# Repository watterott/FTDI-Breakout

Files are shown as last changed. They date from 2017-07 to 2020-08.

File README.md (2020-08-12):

# FTDI-Breakout
The FTDI-Breakout is an USB to Serial Adapter with FTDI Chipset.

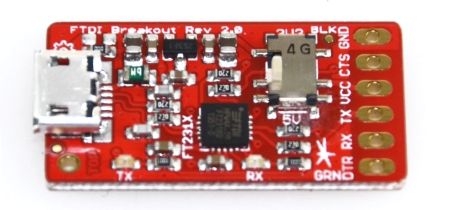
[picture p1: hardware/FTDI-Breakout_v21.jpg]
FTDI-Breakout v2

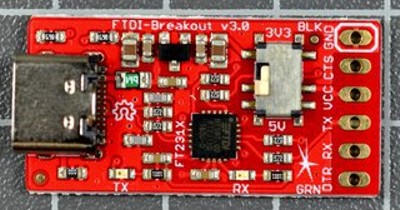
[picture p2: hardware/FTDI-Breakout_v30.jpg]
FTDI-Breakout v3


* [FTDI FT231X](https://www.ftdichip.com/Products/ICs/FT231X.html) USB UART Bridge (up to 1M baud)
* 3.3V or 5V logic supply voltage selectable by switch
* Rx + Tx Status LEDs
* Overcurrent protection (resettable polyswitch fuse)
* Standard 6 pin connector with GND, CTS, VCC, TX, RX, DTR
* USB connector
* Open-Source and released under the [Creative Commons Attribution Share-Alike License](https://creativecommons.org/licenses/by-sa/4.0/).
* **[Documentation on learn.watterott.com](https://learn.watterott.com)**

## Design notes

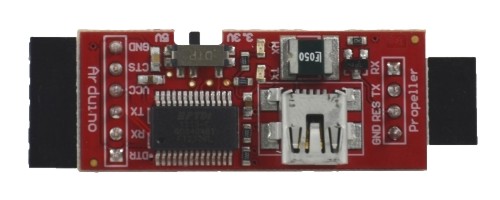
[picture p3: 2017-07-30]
hardware/FTDI-Breakout_v12.jpg

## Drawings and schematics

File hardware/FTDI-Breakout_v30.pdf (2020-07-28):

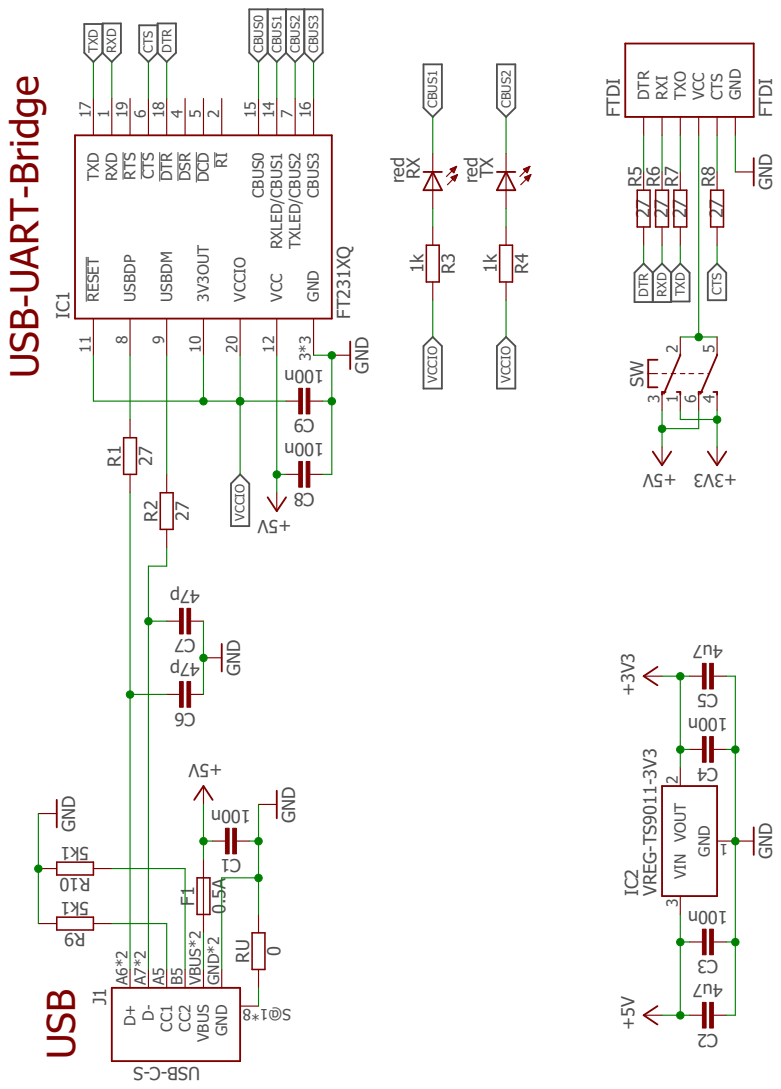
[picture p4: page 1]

Released under the Creative Commons Attribution Share-Alike

Watterott Watterott OS HW CE WEEE

License. http://creativecommons.org/licenses/by-sa/4.0/ Designed by Andreas Watterott (Watterott electronic)

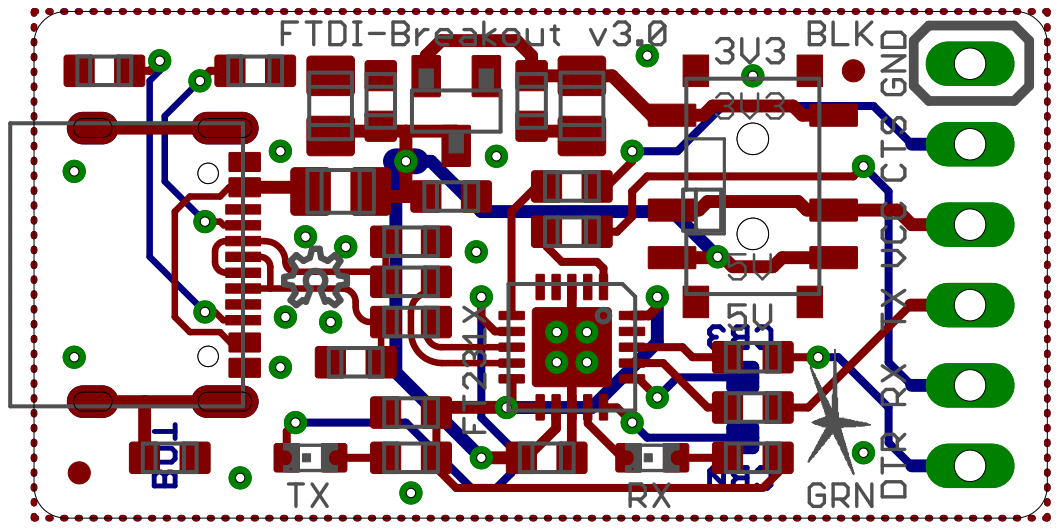
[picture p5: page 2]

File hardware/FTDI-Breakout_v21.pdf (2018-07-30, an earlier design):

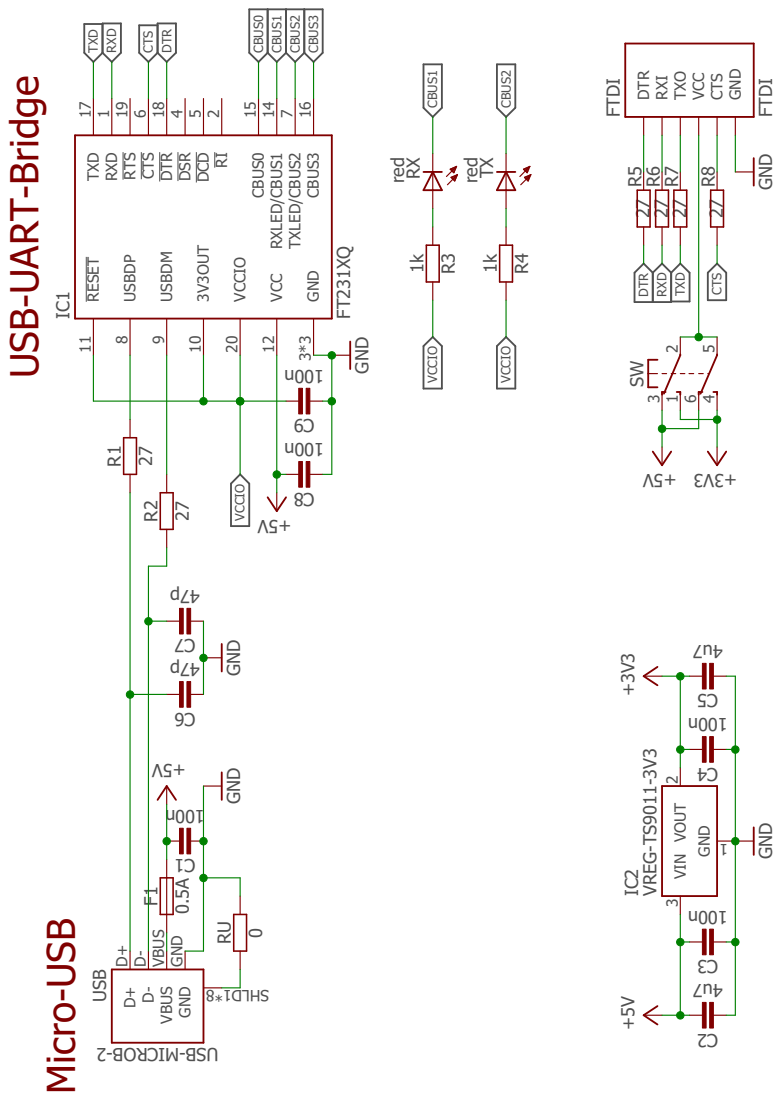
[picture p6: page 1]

FT231XQ 0.5A V5 + GND GND V5 + GND +3V3 +5V 27272727 GND V5 + 3V3 + n001 n001 7u4 27 27 n001 0 red 1k red 1k n001 n001 7u4 p74 p74 GND VREG-TS9011-3V3 Released under the Creative Commons Attribution Share-Alike License. http://creativecommons.org/licenses/by-sa/4.0/ Designed by Andreas Watterott (Watterott electronic) IC13V3OUT 10 USBDM 9 USBDP 8 RESET 11 GND 3*3 TXD 17 RXD 1 RTS 19 CTS 6 DTR 18 DSR 4 DCD 5 RI 2 CBUS0 15 VCCIO 20 VCC 12 RXLED/CBUS1 14 TXLED/CBUS2 7 CBUS3 16 F1 D+ D+ D- D- VBUS VBUS GND GND USB 2- BORCI M- BSU8*1DL HS FTDI FTDI DTR RXI TXO VCC CTS GND 2 31 SW 5 64 R5R6R7R8 3C4C5C R1 R2 1C RU RX R3 TX R4 8C9C 2C 6C7C IC2 GND VIN 3 V1 OUT 2 Watterott Watterott OS HW CE WEEE VCCIO VCCIO VCCIO CTS CTS DTR DTR CBUS0 CBUS1 CBUS1 CBUS2 CBUS2 CBUS3 TXD TXD RXD RXD USB-UART-Bridge Micro-USB ABCD 1 2 3 4 5 6 ABCD 1 2 3 4 5 6

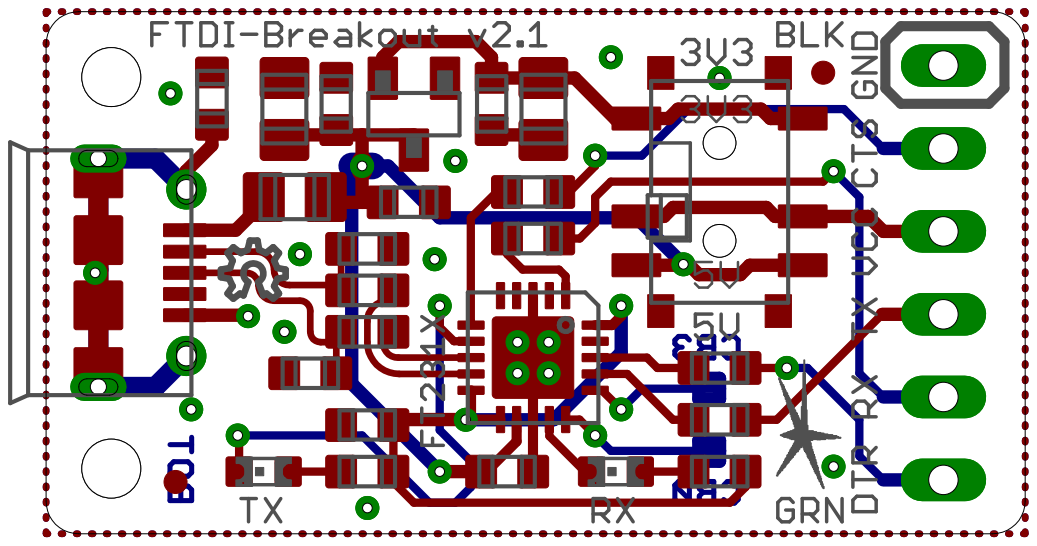
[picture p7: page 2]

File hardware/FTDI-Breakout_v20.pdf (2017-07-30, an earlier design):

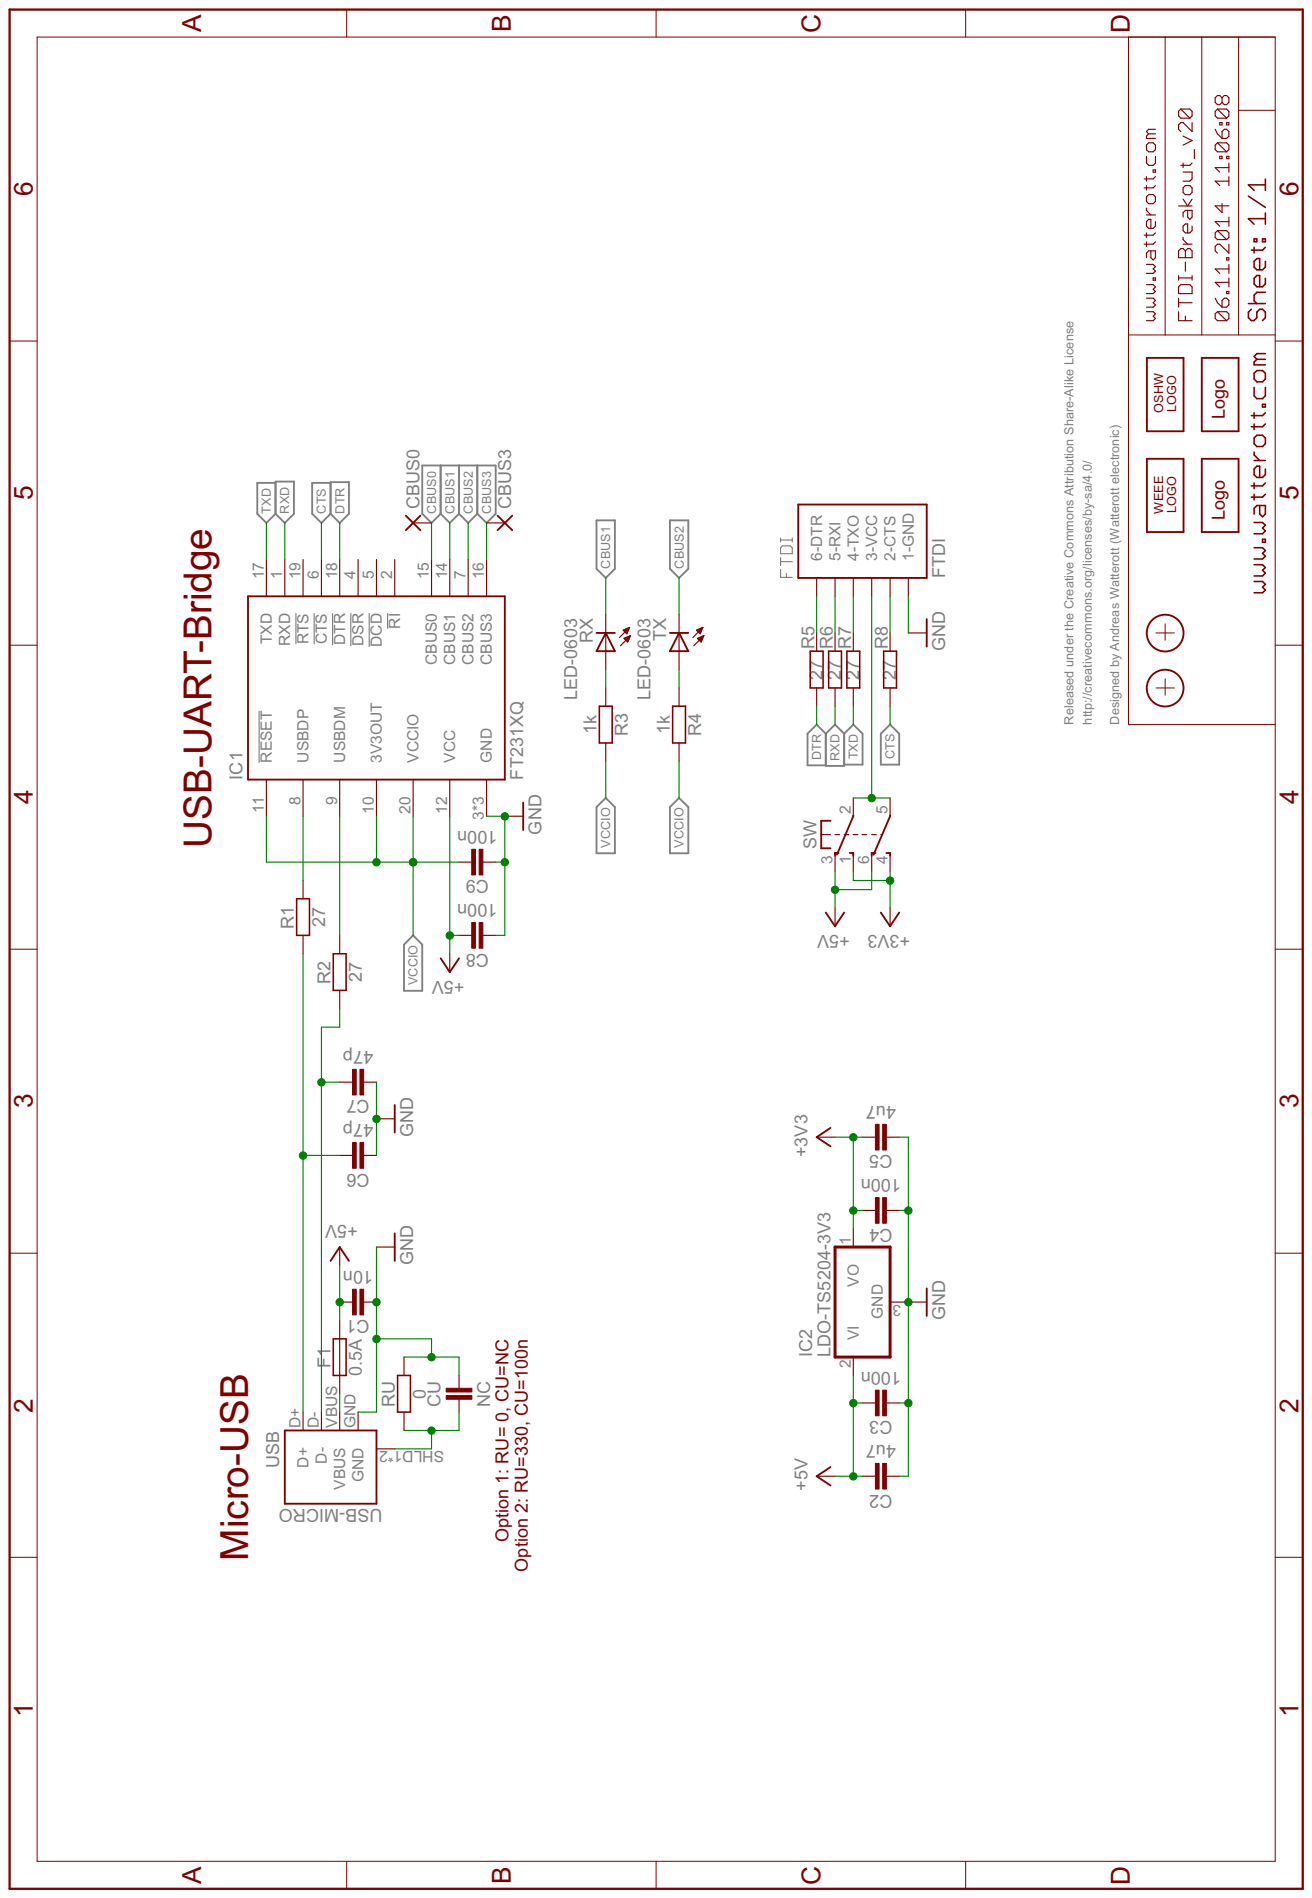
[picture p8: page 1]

FT231XQ LDO-TS5204-3V3 0.5A V5+ GND GND V5+ GND +3V3 +5V 27272727 GND V5+ 3V3+ n001 n001 7u4 27 27 n01 N0C LED-0603 1k LED-0603 1k n001 n001 7u4 p74 p74 GND Released under the Creative Commons Attribution Share-Alike License http://creativecommons.org/licenses/by-sa/4.0/ Designed by Andreas Watterott (Watterott electronic) IC13V3OUT 10 USBDM 9 USBDP 8 RESET 11 GND 3*3 TXD 17 RXD 1 RTS 19 CTS 6 DTR 18 DSR 4 DCD 5 RI 2 CBUS0 15 VCCIO 20 VCC 12 CBUS1 14 CBUS2 7 CBUS3 16 IC2 GND VI 2 3 VO 1 F1 D+ D+ D- D- VBUS VBUS GND GND USB ORCI M- BSU2* 1DLHS FTDI 6-DTR 5-RXI 4-TXO 3-VCC 2-CTS 1-GND 2 31 SW 5 64 R5R6R7R8 3C4C5C R1 R2 1C CURU RX R3 TX R4 8C9C 2C CBUS0 CBUS3 6C7C VCCIO VCCIO VCCIO CTS CTS DTR DTR CBUS0 CBUS1 CBUS1 CBUS2 CBUS2 CBUS3 TXD TXD RXD RXD Option 1: RU= 0, CU=NC Option 2: RU=330, CU=100n USB-UART-Bridge Micro-USB ABCD 1 2 3 4 5 6 ABCD 1 2 3 4 5 6 OSHW LOGO WEEE LOGO Logo Logo

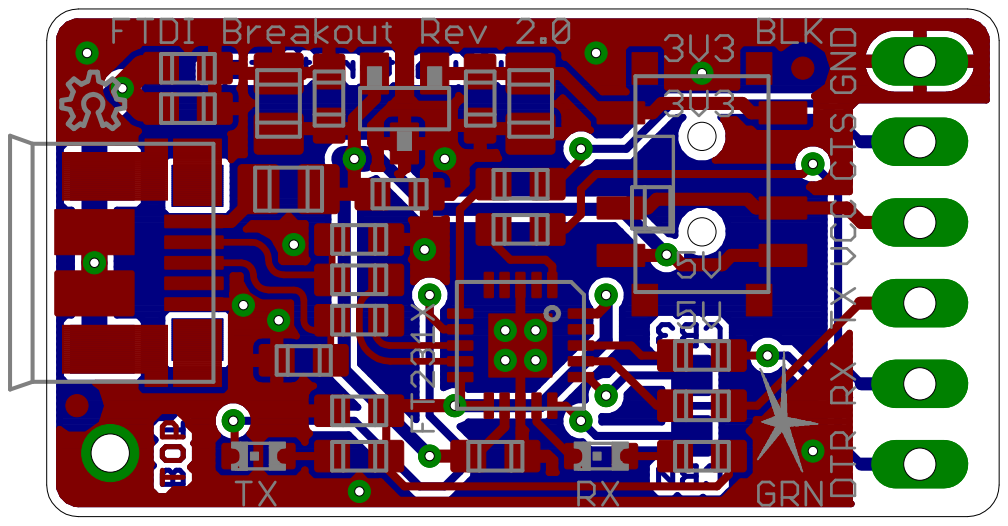
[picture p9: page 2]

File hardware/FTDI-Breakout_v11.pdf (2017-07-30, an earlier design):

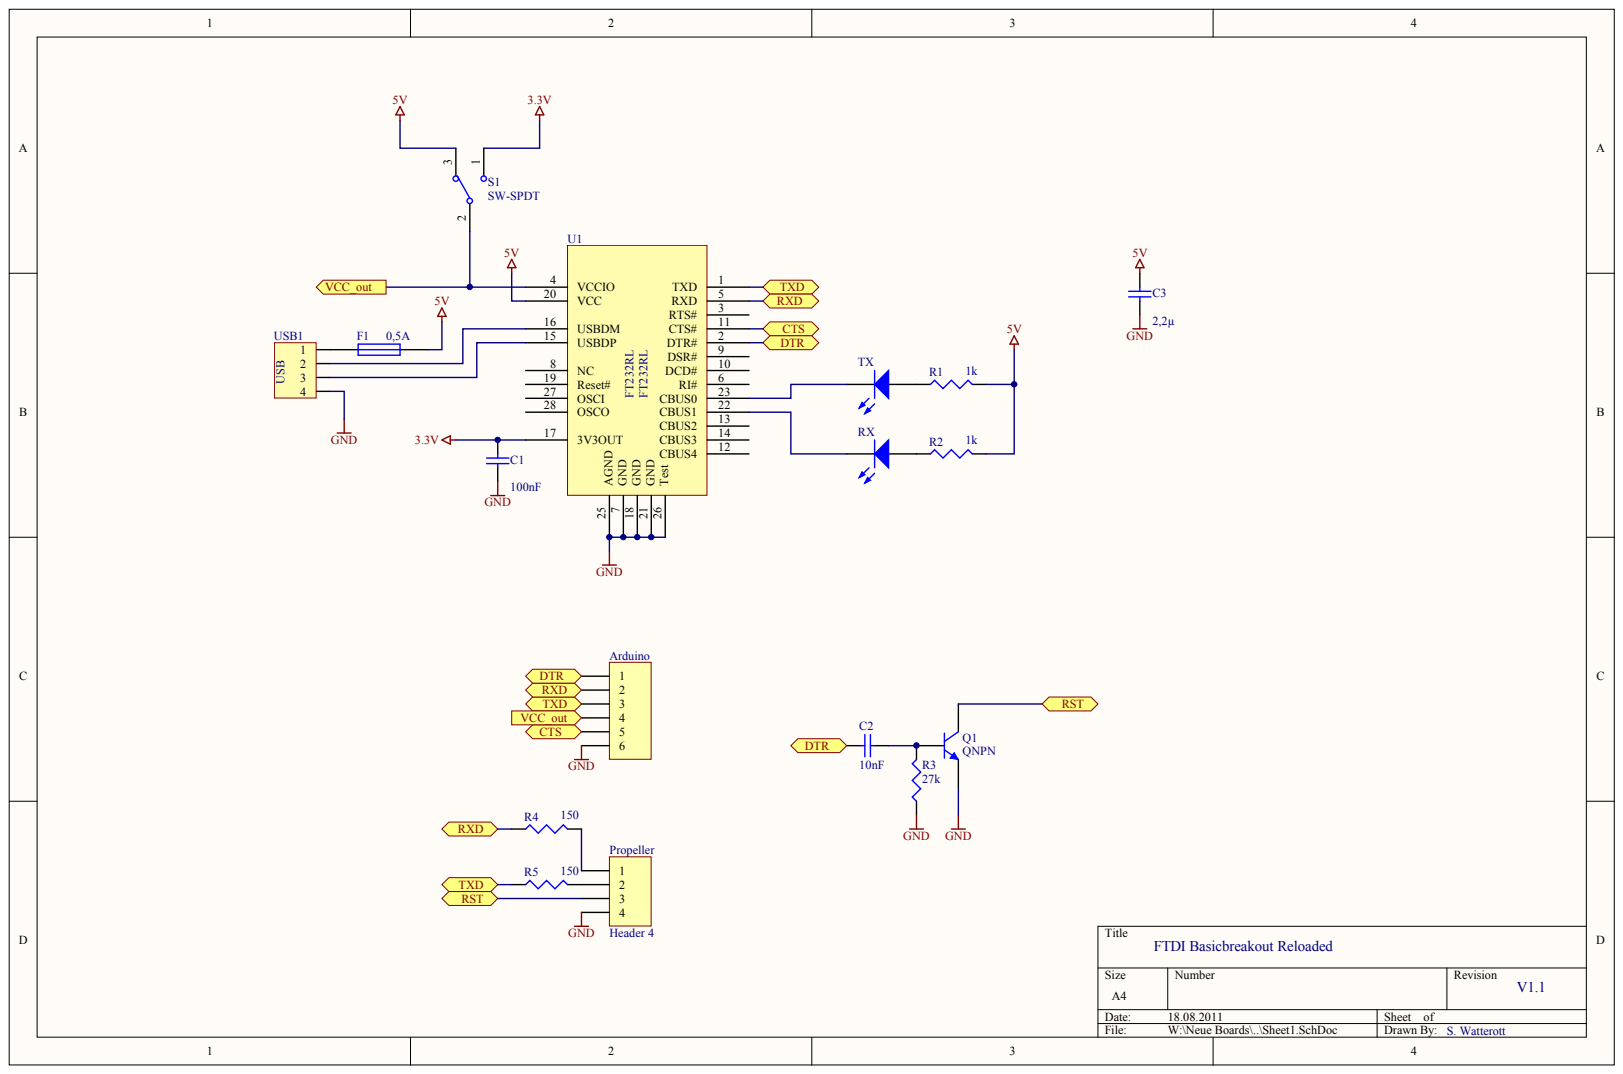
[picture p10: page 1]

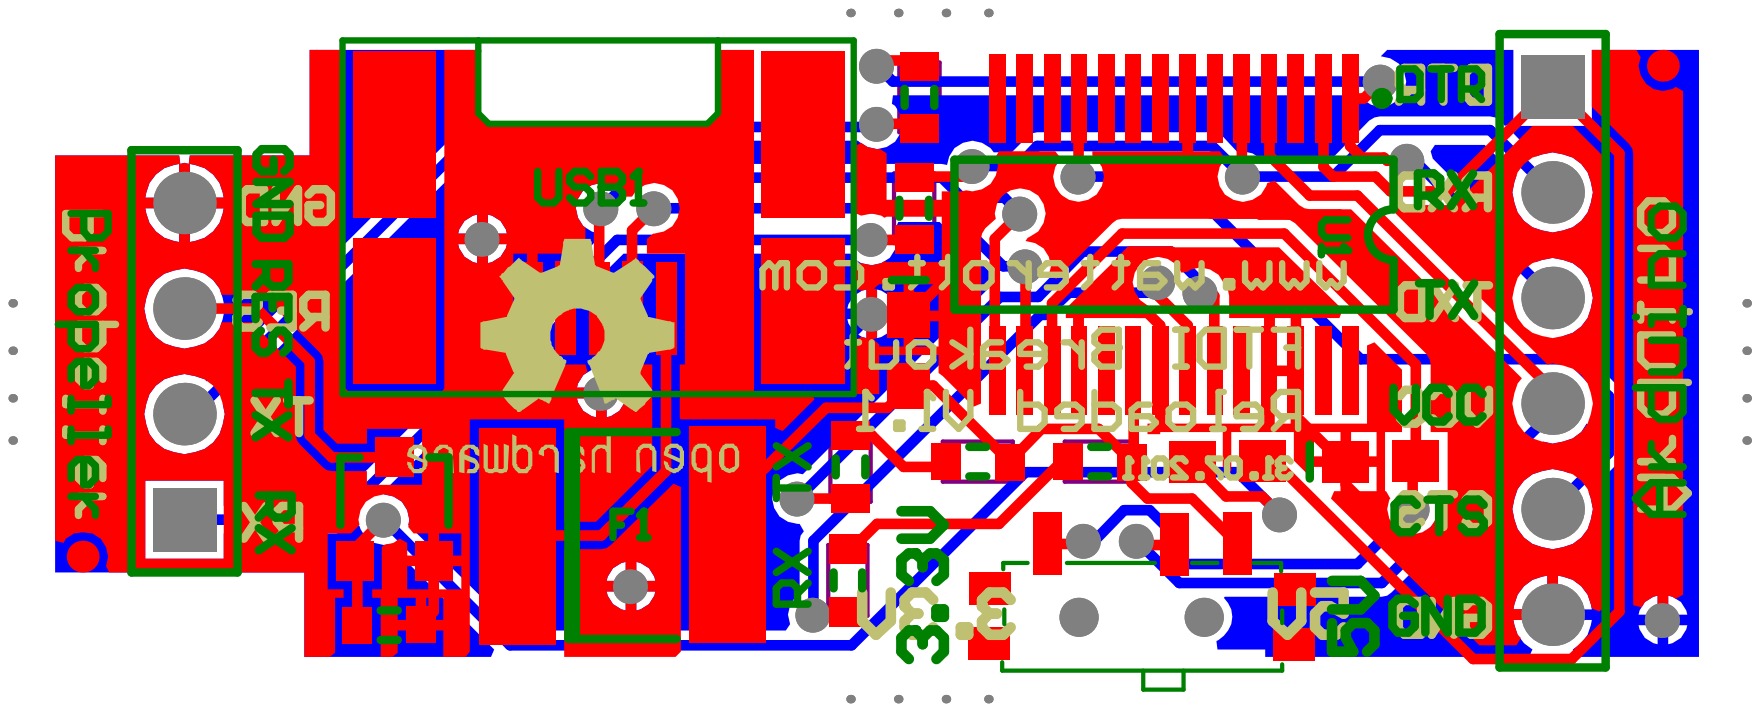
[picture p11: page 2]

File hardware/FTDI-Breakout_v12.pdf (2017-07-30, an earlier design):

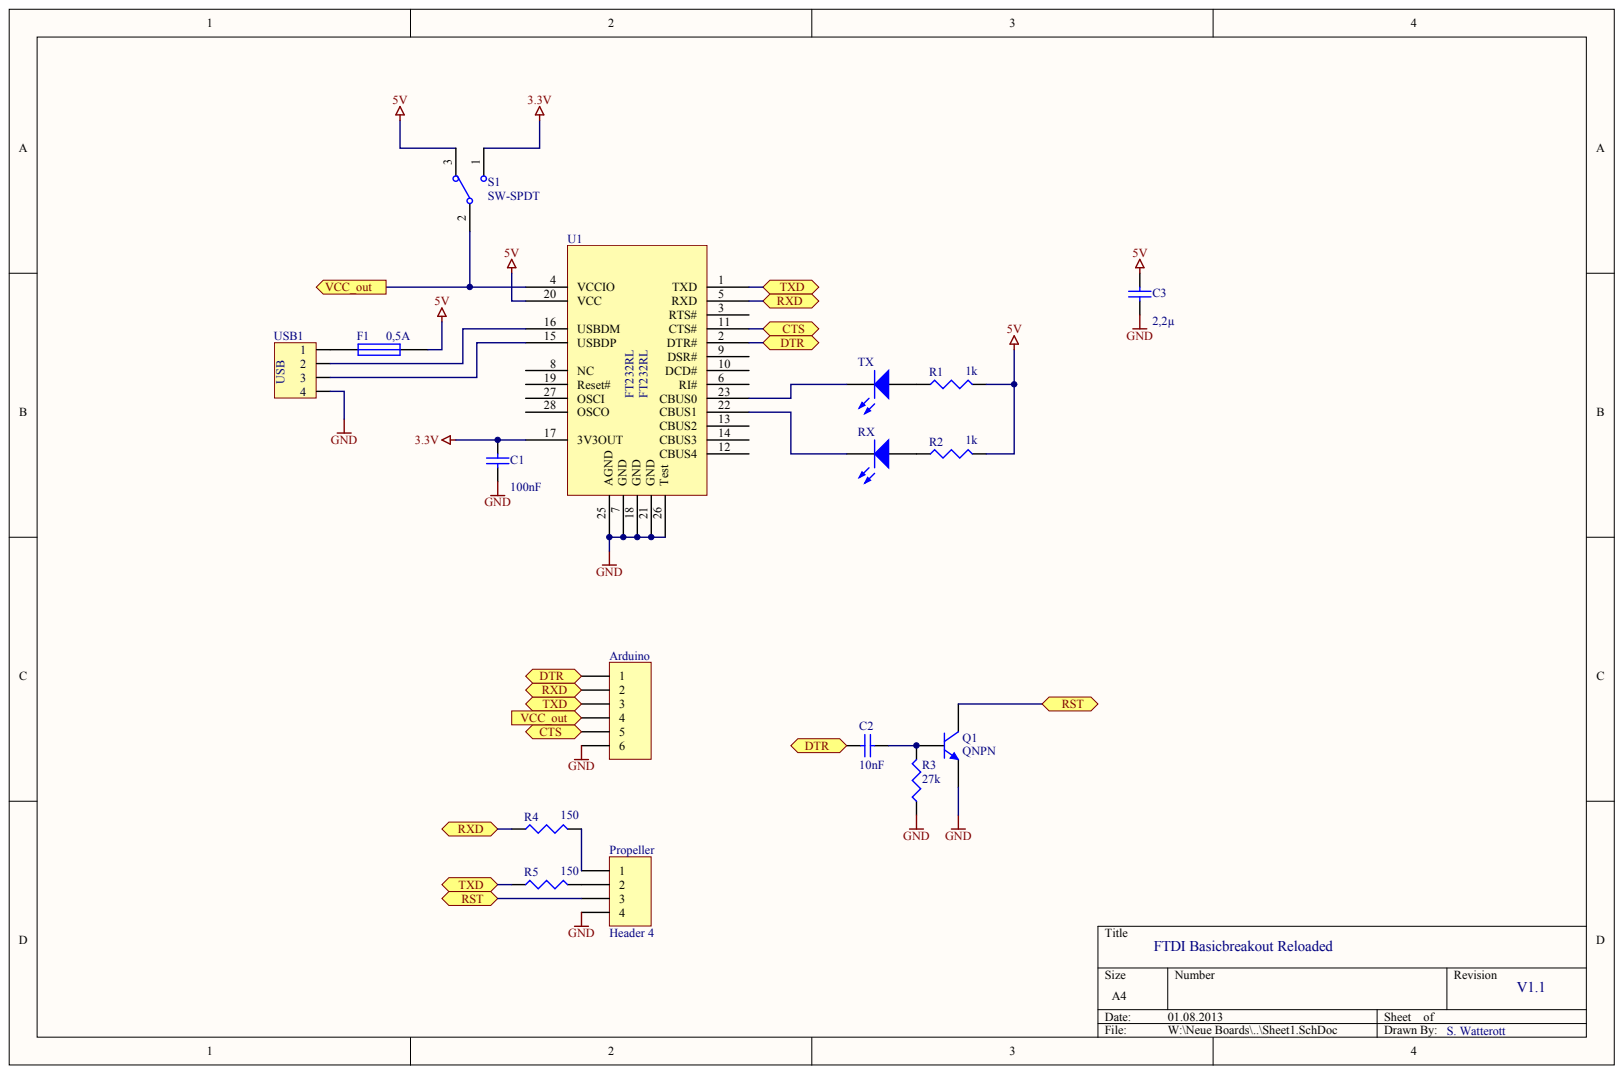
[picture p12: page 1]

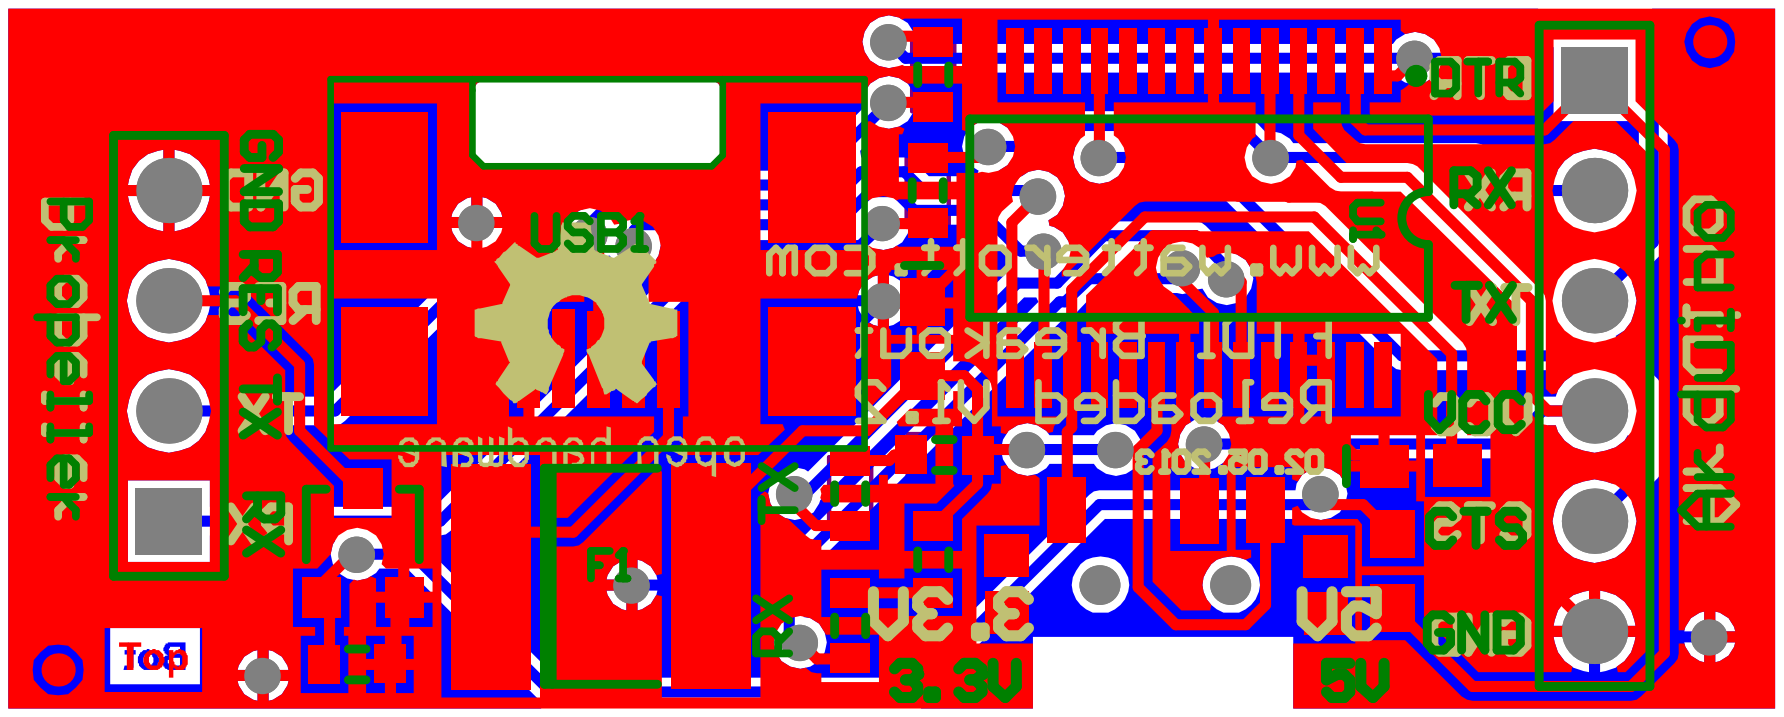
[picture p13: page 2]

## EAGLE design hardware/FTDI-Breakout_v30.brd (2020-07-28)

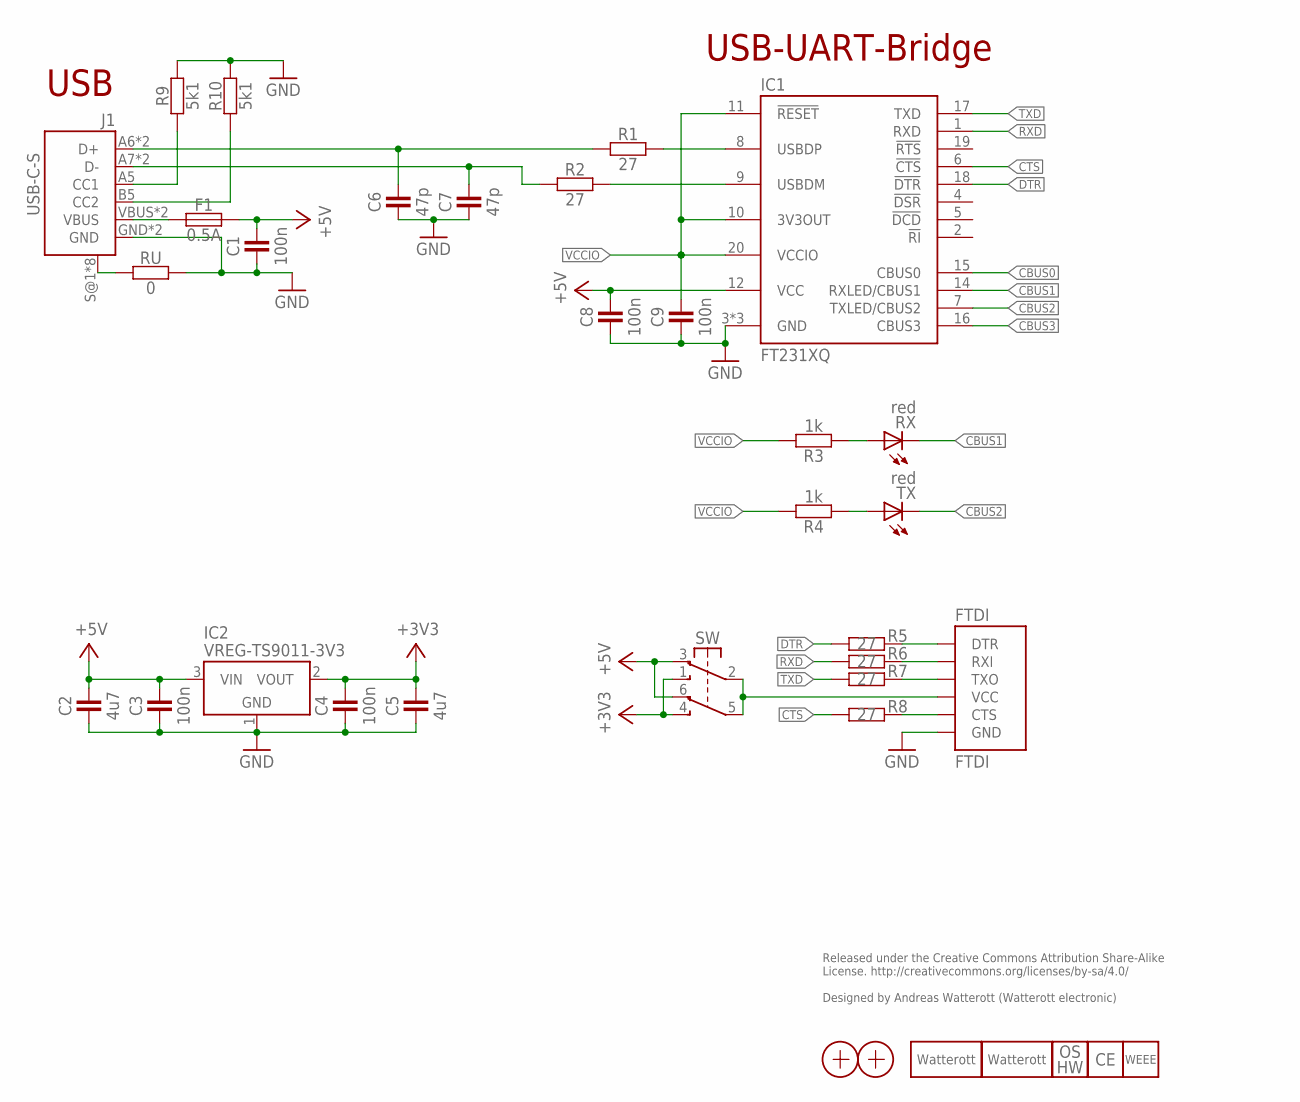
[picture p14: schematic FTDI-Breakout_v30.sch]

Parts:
C1, C3, C4, C8, C9: 100n; C0603
C2, C5: 4u7; C0805
C6, C7: 47p; C0603
F1: 0.5A; C0805
FTDI: FTDI
IC1: FT231XQ; QFN20-PAD
IC2: VREG-TS9011-3V3; SOT23
J1: USB-C-S
LOGO5: LOGO_SPARK-2; SPARK_2MM
LOGO6: LOGO_SPARK-4; SPARK_4MM
LOGO7: LOGO_OSHW-2; OSHW_2MM
LOGO8: LOGO_CE-2; CE_2MM
LOGO9: LOGO_WEEE-4; WEEE_4MM
R1, R2, R5, R6, R7, R8: 27; C0603
R3, R4: 1k; C0603
R9, R10: 5k1; C0603
RU: 0; C0603
RX: red; C0603
SW: SW-2UM-CUS22B; CUS22B
TX: red; C0603
X1, X2: PASSER-07; PASSER_07MM

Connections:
+3V3: C4.2, C5.2, IC2.2 (VOUT), SW.1 (NO1), SW.4 (NO2)
+5V: C1.2, C2.2, C3.2, C8.2, F1.2, IC1.12 (VCC), IC2.3 (VIN), SW.3 (NC1), SW.6 (NC2)
CBUS0: IC1.15 (CBUS0)
CBUS1: IC1.14 (RXLED/CBUS1), RX.C
CBUS2: IC1.7 (TXLED/CBUS2), TX.C
CBUS3: IC1.16 (CBUS3)
CC1: J1.A5 (CC1), R9.1
CC2: J1.B5 (CC2), R10.1
CTS: IC1.6 (!CTS), R8.1
D2_N: IC1.9 (USBDM), R2.2
D2_P: IC1.8 (USBDP), R1.2
DTR: IC1.18 (!DTR), R5.1
D_N: C7.2, J1.A7 (D-), J1.B7 (D-), R2.1
D_P: C6.2, J1.A6 (D+), J1.B6 (D+), R1.1
FTDI-CTS: FTDI.2-CTS (CTS), R8.2
FTDI-DTR: FTDI.6-DTR (DTR), R5.2
FTDI-RXI: FTDI.5-RXI (RXI), R6.2
FTDI-TXO: FTDI.4-TXO (TXO), R7.2
FTDI-VCC: FTDI.3-VCC (VCC), SW.2 (C1), SW.5 (C2)
GND: C1.1, C2.1, C3.1, C4.1, C5.1, C6.1, C7.1, C8.1, C9.1, FTDI.1-GND (GND), IC1.3 (GND), IC1.13 (GND), IC1.TP (GND), IC2.1 (GND), J1.GND, J1.GND2 (GND), R9.2, R10.2, RU.2
RX-LED: R3.1, RX.A
RXD: IC1.1 (RXD), R6.1
SHLD: J1.S@1 (SHIELD), J1.S@2 (SHIELD), J1.S@3 (SHIELD), J1.S@4 (SHIELD), J1.S@5 (SHIELD), J1.S@6 (SHIELD), J1.S@7 (SHIELD), J1.S@8 (SHIELD), RU.1
TX-LED: R4.1, TX.A
TXD: IC1.17 (TXD), R7.1
VBUS: F1.1, J1.VBUS, J1.VBUS2 (VBUS)
VCCIO: C9.2, IC1.10 (3V3OUT), IC1.11 (!RESET), IC1.20 (VCCIO), R3.2, R4.2

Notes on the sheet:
Released under the Creative Commons Attribution Share-Alike License. http://creativecommons.org/licenses/by-sa/4.0/ Designed by Andreas Watterott (Watterott electronic)
USB-UART-Bridge
USB

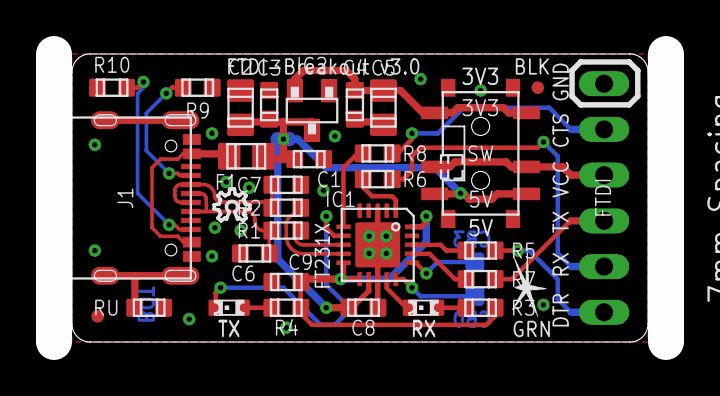
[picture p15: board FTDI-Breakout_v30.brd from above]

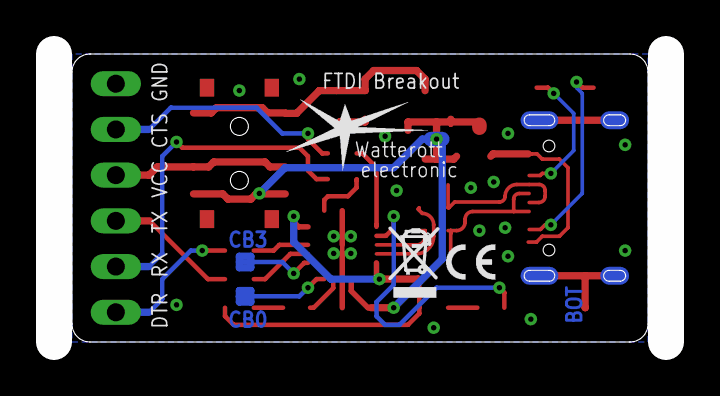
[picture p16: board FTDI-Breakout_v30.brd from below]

Board: 2 copper layers, 34.0 x 16.0 mm, 35 parts (3 on the bottom side), 25 nets.

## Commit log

2018-07-30 added rev 2.1
    [FTDI-Breakout_v21.brd, FTDI-Breakout_v21.sch]
2018-10-27 updated schematics
    [FTDI-Breakout_v21.brd]
2020-07-28 added rev 3.0 (USB-C)
    [FTDI-Breakout_v30.brd, FTDI-Breakout_v30.sch]
